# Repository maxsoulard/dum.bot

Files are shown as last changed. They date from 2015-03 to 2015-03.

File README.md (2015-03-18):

# dum.bot

Small two wheels robot controlled through a webapp or autonomous with ultrasonic sensor. 









<b>Parts</b>

<ul>
<li>Raspberry pi B</li>
<li>Pi camera</li>
<li>Adafruit Trinket</li>
<li>HC-SR04</li>
<li>Pololu Zumo chassis kit with 4xAA to power the motors and the Trinket</li>
<li>Micro metal gearmotor HP 75:1</li>
<li>L298N breakout board</li>
<li>USB battery pack 5000mAh (to power the Pi)</li>
<li>2x servo motor tower pro SG90 (yet to implement)</li>
<li>USB WiFi dongle</li>
<li>Some resistances, breadboards and wires</li>
</ul>

<b>Software</b>

Majority of source code is in python. For the webapp, CherryPy is used (minimalist web framework) and some Javascript (jQuery) for client side code : ajax requests are sent to activate wanted motors (Pi’s GPIO set to HIGH). A second ajax request is sent when the key or touch screen is released to set the Pi’s GPIO to LOW. It stops the activated motors.

RPi.GPIO to control motors via pi’s gpio. For turning right and left functions, I had to use à time.sleep because there was too much lag to have a precise control on turning functions. Now I just turn for 100 m, no matter how long the key is pressed.

Mjpeg-streamer was used for Pi camera streaming (tutos found online). There is a slight lag but it is all devices compatible without any codecs (it is basically an img tag which is constantly refreshed).

Adafruit_I2C library to get datas from the Adafruit Trinket which control the HC-SR04 via I2C.

Arduino code is pretty simple. I will add a servomotor soon but the Trinket has no hardware PWM implementation, so maybe I’ll replace it by a Arduino Nano like.

A simple algorithm to avoid detected obstacle thanks to datas sent by the Trinket. Basically, if an obstacle is closer than 10 centimeters, dum.bot goes back for 200 ms then turn left. If another obstacle is detected, it tries left again. If the way is still not clear, it turns right to check it out. To have a more precise value for obstacle range, it reads 5 values, then removes the min and max values and calculate the average from the 3 left.

<b>Electronic</b> (.fzz in docs)

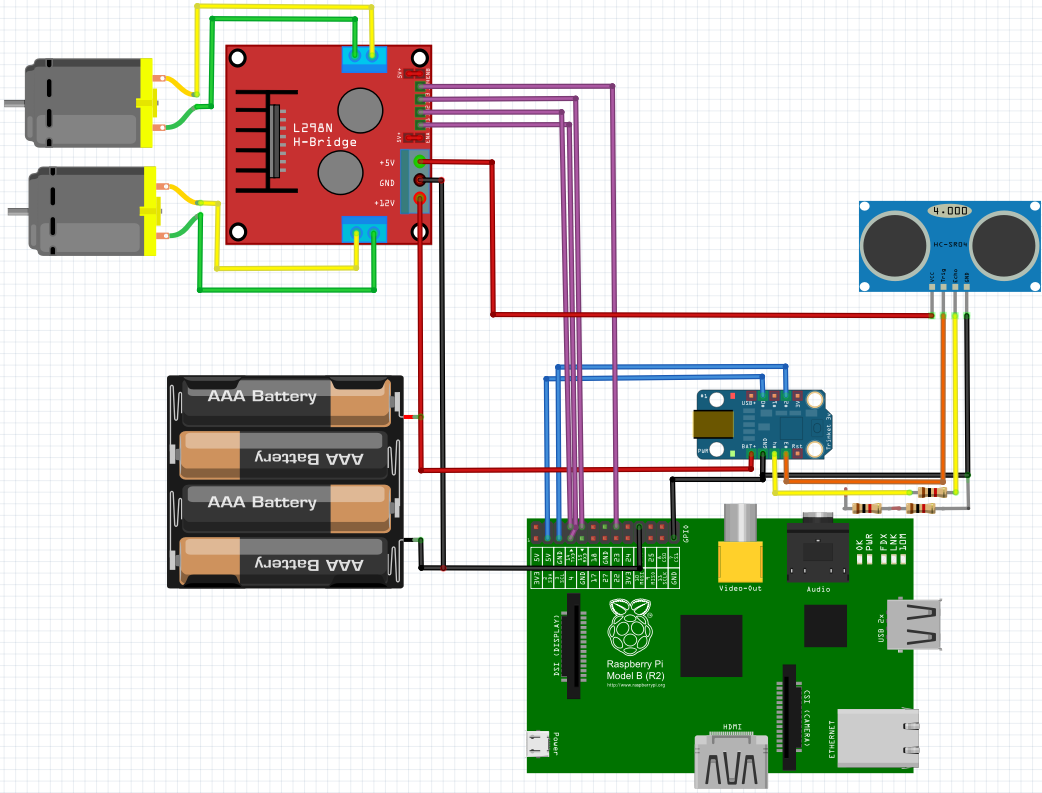
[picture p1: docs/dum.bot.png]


<b>TODO</b>

<ul>
<li>Add servo on HC-SR04</li>
<li>Replace Trinket by Nano</li>
<li>Correct or remove pi camera servos control</li>
<li>Complete install.sh script</li>
<li>Add infrared LED</li>
<li>Add void sensor on the front</li>
</ul>

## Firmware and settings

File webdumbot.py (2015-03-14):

# -*- encoding: utf8 -*-

import os

import cherrypy
from utilssys import *
from cherrypy.lib.static import serve_file
from gpiodcmotors import *
from gpioservo import *
from constantes import *
from obstacleavoider import Obstacleavoider


path = os.path.abspath(os.path.dirname(__file__))


class Webdumbot(object):
    def __init__(self):
        self.gpiodcmotors = Gpiodcmotors()
        self.gpioservo = Gpioservo()
        self.obstaclethread = Obstacleavoider('Auto thread')

    @cherrypy.expose
    def index(self):
        return serve_file(os.path.join(path, 'index.html'))

    @cherrypy.expose
    @cherrypy.tools.json_out()
    def goForward(self):
        print("FORWARD")
        self.gpiodcmotors.triggerForward()

    @cherrypy.expose
    @cherrypy.tools.json_out()
    def goBackward(self):
        print("BACKWARD")
        self.gpiodcmotors.triggerBackward()


    @cherrypy.expose
    @cherrypy.tools.json_out()
    def turnLeft(self):
        print("LEFT")
        self.gpiodcmotors.triggerLeft()


    @cherrypy.expose
    @cherrypy.tools.json_out()
    def turnRight(self):
        print("RIGHT")
        self.gpiodcmotors.triggerRight()

    # GESTION DES SERVOS CAM

    @cherrypy.expose
    @cherrypy.tools.json_out()
    def camUp(self):
        # TODO cam up and down
        # if self.gpioservo.servo2.direction != Constantes.CAMUP:
        #     self.gpioservo.servo2.direction = Constantes.CAMUP
        #     self.gpioservo.upDownCam()
        # else:
        #     self.gpioservo.servo2.direction = None
        pass

    @cherrypy.expose
    @cherrypy.tools.json_out()
    def camDown(self):
        # TODO cam up and down
        # if self.gpioservo.servo2.direction != Constantes.CAMDOWN:
        #     self.gpioservo.servo2.direction = Constantes.CAMDOWN
        #     self.gpioservo.upDownCam()
        # else:
        #     self.gpioservo.servo2.direction = None
        pass

    @cherrypy.expose
    @cherrypy.tools.json_out()
    def camLeft(self):
        if self.gpioservo.servo1.direction != Constantes.CAMLEFT:
            self.gpioservo.servo1.direction = Constantes.CAMLEFT
            self.gpioservo.turnCam()
        else:
            self.gpioservo.servo1.direction = None

    @cherrypy.expose
    @cherrypy.tools.json_out()
    def camRight(self):
        if self.gpioservo.servo1.direction != Constantes.CAMRIGHT:
            self.gpioservo.servo1.direction = Constantes.CAMRIGHT
            self.gpioservo.turnCam()
        else:
            self.gpioservo.servo1.direction = None

    @cherrypy.expose
    @cherrypy.tools.json_out()
    def camCenter(self):
        if self.gpioservo.servo1.direction != Constantes.CAMCENTER:
            self.gpioservo.servo1.direction = Constantes.CAMCENTER
            self.gpioservo.centerCam()
        else:
            self.gpioservo.servo1.direction = None

    def cancelCam(self):
        self.gpioservo.cancel()

    # FIN GESTION SERVOS CAM

    @cherrypy.expose
    @cherrypy.tools.json_out()
    def resetGpio(self):
        print("resetGpio")
        self.gpiodcmotors.reset()
        raise cherrypy.HTTPRedirect("/")


    @cherrypy.expose
    @cherrypy.tools.json_out()
    def stop(self):
        print("stop")
        self.gpiodcmotors.stop()
        Utilssys.killcampr()
        exit()

    @cherrypy.expose
    @cherrypy.tools.json_out()
    def modeAuto(self):
        print("mode auto")
        # self.gpiodcmotors.triggerForward()
        # self.autothread = threading.Thread(target=self.launchautothread)
        if not self.obstaclethread.paused:
            self.obstaclethread.start()
        else:
            self.obstaclethread.resume()

    @cherrypy.expose
    @cherrypy.tools.json_out()
    def modeManuel(self):
        print("mode manuel")
        self.obstaclethread.pause()

    index.exposed = True

if __name__ == '__main__':
    cherrypy.config.update({'server.socket_host': '0.0.0.0'})

    conf = {
        '/': {
            'tools.sessions.on': True,
            'tools.staticdir.root': os.path.abspath(os.getcwd())
        },
        '/static': {
            'tools.staticdir.on': True,
            'tools.staticdir.dir': './public'
        },
        'global':{
            'server.socket_port': 8079
        }
    }
    cherrypy.quickstart(Webdumbot(), '/', conf)

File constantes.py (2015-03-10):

class Constantes():

    # Gestion camera i2c
    CAMLEFT = 'l'
    CAMRIGHT = 'r'
    CAMUP = 'u'
    CAMDOWN = 'd'
    CAMCENTER = 'c'

    I2C_INIT = 0x40
    I2C_TRINKET1ADR = 0x04
    I2C_TIMESLEEP = 0.050


    # Moteurs
    SERVO1PIN = 18
    SERVO2PIN = 22


    # Autres
    PORT_CAM_PR = 8083

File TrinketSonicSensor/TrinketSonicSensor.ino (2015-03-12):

#include <TinyWireS.h>
#include <Adafruit_SoftServo.h>  // SoftwareServo (works on non PWM pins)

#define I2C_SLAVE_ADDRESS 0x04
#define PIN_TRIG 4
#define PIN_ECHO 3
#define SERVO1PIN 1

//Adafruit_SoftServo myServo1;
//int16_t  servo1Position;

byte reg[] = {0x00, 0x00};
byte reg_idx = 0;

long lecture_echo;
long cm;

void onRequest()
{
  TinyWireS.send(reg[reg_idx]);
  reg_idx = (reg_idx == 1) ? 0 : 1; 
}

void setup()
{
    // Servomotor setup
    /*OCR0A = 0xAF;            // any number is OK
    TIMSK |= _BV(OCIE0A);    // Turn on the compare interrupt (below!)
    myServo1.attach(SERVO1PIN);   // Attach the servo to pin 1 on Trinket
    servo1Position = 20;
    myServo1.write(servo1Position);
    tws_delay(200);
    servo1Position = 120;
    myServo1.write(servo1Position);
    tws_delay(200);*/
    
    // I2C setup
    TinyWireS.begin(I2C_SLAVE_ADDRESS);
    TinyWireS.onRequest(onRequest);
    
    // HC-SR04 setup
    pinMode(PIN_TRIG, OUTPUT);
    digitalWrite(PIN_TRIG, LOW);
    pinMode(PIN_ECHO, INPUT);
}

void loop()
{
    digitalWrite(PIN_TRIG, HIGH);
    delayMicroseconds(100);
    digitalWrite(PIN_TRIG, LOW);
    lecture_echo = pulseIn(PIN_ECHO, HIGH);
    cm = lecture_echo / 58;
    
    reg[0] = lowByte(cm);
    reg[1] = highByte(cm);

    TinyWireS_stop_check();
    //myServo1.write(servo1Position+40);
    //tws_delay(15);
}

// Adafruit :
// We'll take advantage of the built in millis() timer that goes off
// to keep track of time, and refresh the servo every 20 milliseconds
// The SIGNAL(TIMER0_COMPA_vect) function is the interrupt that will be
// Called by the microcontroller every 2 milliseconds
/*volatile uint8_t counter = 0;
SIGNAL(TIMER0_COMPA_vect) {
    // this gets called every 2 milliseconds
    counter += 2;
    // every 20 milliseconds, refresh the servos!
    if (counter >= 20) {
      counter = 0;
      myServo1.refresh();
    }
}*/

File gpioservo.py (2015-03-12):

import time
import os
import wiringpi2 as wiringpi
from constantes import *


class ServoPwm():
    def __init__(self, pin):
        self.dtMin, self.dtMax, self.dtMed = 35, 120, 65
        self.dt = self.dtMed
        self.pin = pin
        self.direction = ''
        wiringpi.wiringPiSetupGpio()
        wiringpi.pinMode(self.pin, 2)
        wiringpi.pwmSetMode(0)
        wiringpi.pwmSetClock(400)
        wiringpi.pwmSetRange(1024)
        try:
            wiringpi.pwmWrite(self.pin, 40)
        except Exception as e:
            print str(e)

    def determineval(self, dtemp):
        if dtemp > self.dtMax:
            self.dt = self.dtMax
        elif dtemp < self.dtMin:
            self.dt = self.dtMin
        else:
            self.dt = dtemp

    def pwmwrite(self):
        wiringpi.pwmWrite(self.pin, self.dt)
        print "PIN "+str(self.pin)+"DT = "+str(self.dt)


# class ServoSoftPwm():
#     def __init__(self, pin):
#         self.min, self.max, self.med = 1, 30, 15
#         self.val = self.med
#         self.pin = pin
#         self.direction = ''
#         os.system('sudo /home/pi/pi-blaster/pi-blaster '+str(self.pin))
#         valtemp = self.med / float(100)
#         os.system('echo "%d=%f" > /dev/pi-blaster' % (self.pin, valtemp))
#         time.sleep(0.2)
#         os.system('echo "%d=0" > /dev/pi-blaster' % (self.pin))
#
#     def determineval(self, dtemp):
#         if dtemp > self.max:
#             self.val = self.max
#         elif dtemp < self.min:
#             self.val = self.min
#         else:
#             self.val = dtemp
#
#     def pwmwrite(self):
#         valtemp = self.val / float(100)
#         os.system('echo "%d=%f" > /dev/pi-blaster' % (self.pin, valtemp))
#         time.sleep(0.2)
#         os.system('echo "%d=0" > /dev/pi-blaster' % (self.pin))
#         time.sleep(0.2)
#         print "PIN "+str(self.pin)+"valtemp = "+str(valtemp)+"val = "+str(self.val)


class Gpioservo():
    def __init__(self):
        # self.servo1 = ServoPwm(Constantes.SERVO1PIN)
        self.servo1 = ServoPwm(Constantes.SERVO1PIN)
        # self.servo2 = ServoSoftPwm(Constantes.SERVO2PIN)

    def turnCam(self):
        try:
            if self.servo1.direction == Constantes.CAMLEFT:
                print "CAM LEFT"
                valtemp = self.servo1.dt + 10
                self.servo1.determineval(valtemp)
                self.servo1.pwmwrite()

            elif self.servo1.direction == Constantes.CAMRIGHT:
                print "CAM RIGHT"
                valtemp = self.servo1.dt - 10
                self.servo1.determineval(valtemp)
                self.servo1.pwmwrite()

        except Exception as e:
            # clean up
            wiringpi.pwmWrite(Constantes.SERVO1PIN, 0)
            print("exiting.")
            print(str(e))

    def upDownCam(self):
        try:
            pass
            # if self.servo2.direction == Constantes.CAMUP:
            #     print "CAM UP"
            #     valtemp = self.servo2.val - 5
            #     self.servo2.determineval(valtemp)
            #     self.servo2.pwmwrite()
            #
            # elif self.servo2.direction == Constantes.CAMDOWN:
            #     print "CAM DOWN"
            #     valtemp = self.servo2.val + 5
            #     self.servo2.determineval(valtemp)
            #     self.servo2.pwmwrite()

        except Exception as e:
            # clean up
            print("exiting.")
            print(str(e))

    def centerCam(self):
        try:
            if self.servo1.direction == Constantes.CAMCENTER:
                valtemp = 65
                # valtemp2 = 20
                # self.servo1.determineval(valtemp)
                # self.servo1.pwmwrite()
                # self.servo2.determineval(valtemp2)
                # self.servo2.pwmwrite()

        except Exception as e:
            # clean up
            print("exiting.")
            print(str(e))

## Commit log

2015-02-20 Ajout doc électronique
    [dum.bot.fzz]
2015-02-22 trinket ne gère plus qu'1 servo via I2C. TODO : sonar
2015-02-22 Dev servo 1 rpi
2015-02-25 Ajout commande kill process stream pi camera
2015-02-25 kill module pi camera bouton stop
2015-02-26 JQuery + ajax sur buttons
2015-02-26 jquery et ajax pour les buttons
2015-03-02 Test thread servo
2015-03-02 Retour arriere thread
2015-03-08 Cam servo 2 soft pwm
2015-03-09 dev servo
2015-03-11 Servos : utilisation du pwm hardware. Le servo vertical est temporairement abandonné (solution à définir)
2015-03-12 dev trinket i2c
2015-03-12 Trinket sonic sensor - gestion du sr04
2015-03-13 Ajout thread mode auto
2015-03-13 obstacle avoider algo modifications
    [obstacleavoider.py, webdumbot.py]
2015-03-14 dev thread obstacleavoider + algo
2015-03-18 Docs updated
    [dum.bot.fzz]
